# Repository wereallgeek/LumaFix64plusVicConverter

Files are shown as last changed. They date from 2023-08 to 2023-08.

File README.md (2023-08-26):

# LumaFix64 plus 85xx to 65xx VIC-II VDD selection
The LumaFix64 is not my design. 
This work is based on the brilliant work of Sven Peterson https://github.com/svenpetersen1965/LumaFix64
His version is based on <a href="https://www.lemon64.com/forum/viewtopic.php?t=40570&start=375">e5frog's LumaFix64 design</a>, which was released in March 7th, 2018 in the Lemon64.com forum. The changes in my design are:

* Added a VIC-II conversion to enable either shortboard or longboard voltages to the VIC-II, in order to be able to install 85xx VICs to an earlier (longboard) motherboard
* Added jumper to permit bypassing the C64 motherboard and push wires directly to the RF modulator unit (for aftermarker models that accepts it) in order to further reduce induced noise on the video lines

-- this design has not yet been tested

Sven advise that the Chroma potentiometer is not required but most LUMAFIX still includes it. If desired, it can be omitted, but this revision does not prepare solder points to do so, please use the potentiometer connections directly for that purpose. 

The LumaFix64 requires the precision round pin strips, because those are narrow enough not to break the socket of VIC-II chip. Since these pin strips are fragile, the LumaFix64 has to be handle with care.

Permission was initially received from e5frog for publishing these files, which was done in open hardware - the current development further enhance the design in pure open hardware ideology.

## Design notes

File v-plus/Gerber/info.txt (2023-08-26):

      
   
       Board: LumaFix64 v1.1sp (e5frog & http://www.lemon64.com)
       Rev.:  PLUS
  
       Files:
       ======
  
       All Gerber files are generated in extended gerber format (RS274X)
       *.TOP        : Film top copper
       *.BOT        :  -"- bottom copper
       *.STC        :  -"- top soldermask 
       *.STS        :  -"- bottom soldermask
       *.CRC        :  -"- cream top
       *.PLC        :  -"- silk screen top
       *.PLS        :  -"- silk screen bottom
       *.DK         : Drills plated Through (Excellon)
       *.NDK        : Drills not plated Through (Excellon)
       *.OUT        : Board outline

       Board Size:
       ===========
       Length     :   50.75 mm
       Width      :   25.94 mm
       Thickness  :   1.6 mm
       Material   :   FR 4
       Copper     :   35 um
       Surface    :   HASL
       
       Remarks:
       ========
       Drills not plated Through do not exsist on this board.
       drills >= 0.35mm
       width >= 8mil
       distance >= 6mil

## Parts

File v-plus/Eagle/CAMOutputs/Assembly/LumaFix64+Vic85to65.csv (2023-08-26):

Qty | Value | Device | Package | Parts | Description | POPULARITY
1 |  | IC-PACKAGE_DIL40GS40P | GS40P | SOCKET | Dual In Line
1 |  | IC-PACKAGE_DIL40_10120540 | BLK_10120540_2X20 | PINS | Dual In Line
2 |  | JP1E | JP1 | COLOR, S/LUM | JUMPER | 61
1 |  | JP2E | JP2 | SELECT-ONE | JUMPER | 34
1 | 100n | C-0805 | 0805 | C3
3 | 2k | TRIM_US-RJ9W | RJ9W | AEC, CHR, PHI0 | POTENTIOMETER | 1
2 | 47p | C-0805 | 0805 | C1, C2
1 | 74HCT14D | 74HCT14D | SO14 | IC1 | Hex schmitt trigger INVERTER
1 | OPEN_SOURCE_HW | OPEN_SOURCE_HW | OPENHW | U$13

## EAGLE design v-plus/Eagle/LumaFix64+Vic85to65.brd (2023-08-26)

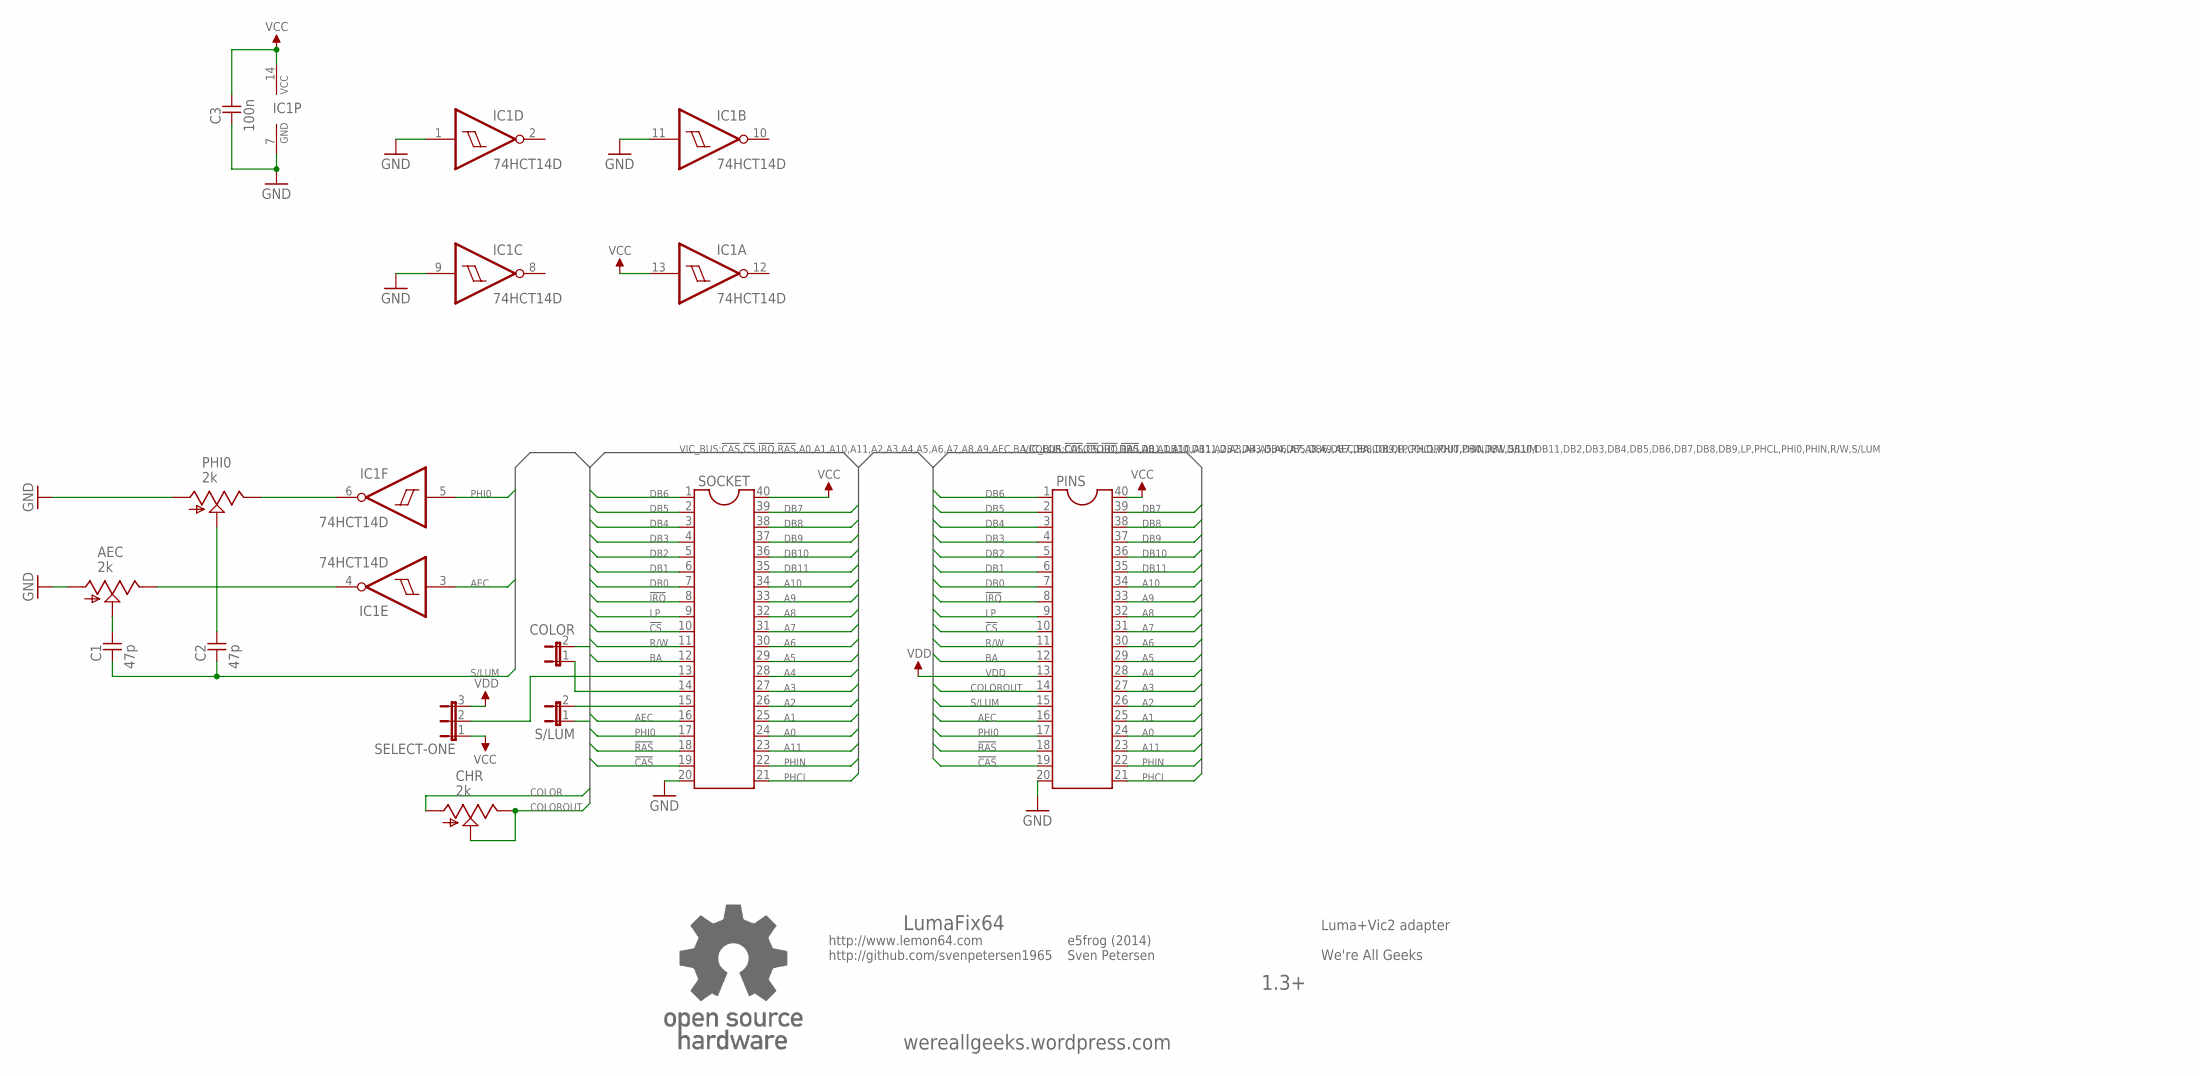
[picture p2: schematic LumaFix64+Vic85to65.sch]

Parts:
AEC: 2k; RJ9W
C1, C2: 47p; 0805
C3: 100n; 0805
CHR: 2k; RJ9W
COLOR: JP1E; JP1
IC1: 74HCT14D; SO14
PHI0: 2k; RJ9W
PINS: IC-PACKAGE_DIL40_10120540; BLK_10120540_2X20
S/LUM: JP1E; JP1
SELECT-ONE: JP2E; JP2
SOCKET: IC-PACKAGE_DIL40GS40P; GS40P
U$13: OPEN_SOURCE_HW; OPENHW

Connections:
!CAS: PINS.19, SOCKET.19
!CS: PINS.10, SOCKET.10
!IRQ: PINS.8, SOCKET.8
!RAS: PINS.18, SOCKET.18
A0: PINS.24, SOCKET.24
A1: PINS.25, SOCKET.25
A2: PINS.26, SOCKET.26
A3: PINS.27, SOCKET.27
A4: PINS.28, SOCKET.28
A5: PINS.29, SOCKET.29
A6: PINS.30, SOCKET.30
A7: PINS.31, SOCKET.31
A8: PINS.32, SOCKET.32
A9: PINS.33, SOCKET.33
A10: PINS.34, SOCKET.34
A11: PINS.23, SOCKET.23
AEC: IC1.3 (I), PINS.16, SOCKET.16
BA: PINS.12, SOCKET.12
COLOR: CHR.A, COLOR.2
COLOROUT: CHR.E, CHR.S, PINS.14
DB0: PINS.7, SOCKET.7
DB1: PINS.6, SOCKET.6
DB2: PINS.5, SOCKET.5
DB3: PINS.4, SOCKET.4
DB4: PINS.3, SOCKET.3
DB5: PINS.2, SOCKET.2
DB6: PINS.1, SOCKET.1
DB7: PINS.39, SOCKET.39
DB8: PINS.38, SOCKET.38
DB9: PINS.37, SOCKET.37
DB10: PINS.36, SOCKET.36
DB11: PINS.35, SOCKET.35
GND: AEC.A, C3.1, IC1.1 (I), IC1.7 (GND), IC1.9 (I), IC1.11 (I), PHI0.A, PINS.20, SOCKET.20
LP: PINS.9, SOCKET.9
unnamed: SELECT-ONE.2, SOCKET.13
unnamed: COLOR.1, SOCKET.14
unnamed: S/LUM.2, SOCKET.15
unnamed: AEC.S, C1.2
unnamed: C2.2, PHI0.S
unnamed: AEC.E, IC1.4 (O)
unnamed: IC1.6 (O), PHI0.E
PHCL: PINS.21, SOCKET.21
PHI0: IC1.5 (I), PINS.17, SOCKET.17
PHIN: PINS.22, SOCKET.22
R/W: PINS.11, SOCKET.11
S/LUM: C1.1, C2.1, PINS.15, S/LUM.1
VCC: C3.2, IC1.13 (I), IC1.14 (VCC), PINS.40, SELECT-ONE.1, SOCKET.40
VDD: PINS.13, SELECT-ONE.3

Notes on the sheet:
LumaFix64
http://www.lemon64.com http://github.com/svenpetersen1965
e5frog (2014) Sven Petersen
1.3+
Luma+Vic2 adapter
We're All Geeks
wereallgeeks.wordpress.com

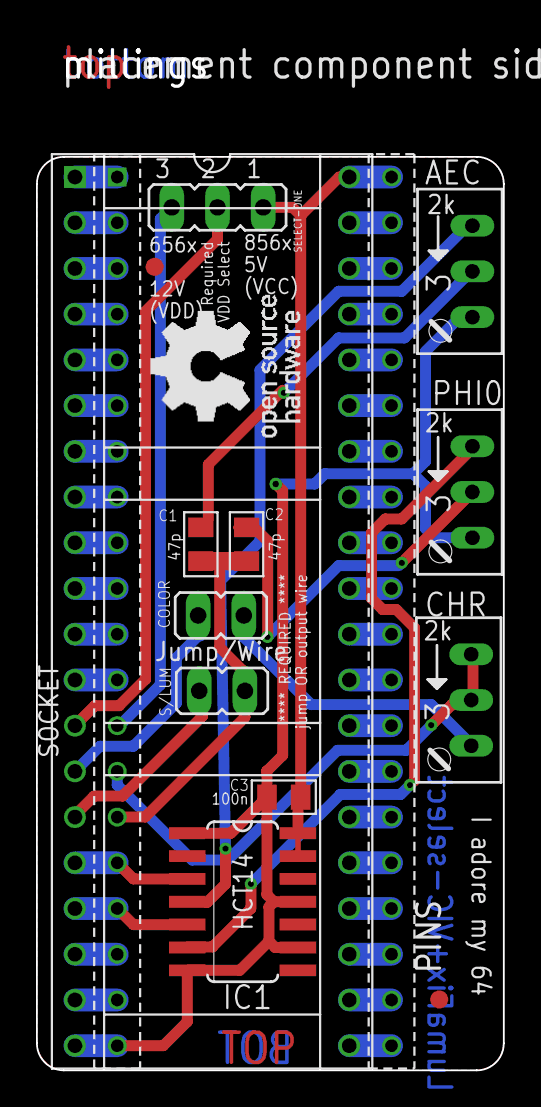
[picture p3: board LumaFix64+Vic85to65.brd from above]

Board: 2 copper layers, 25.9 x 50.8 mm, 17 parts (0 on the bottom side), 48 nets.

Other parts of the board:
U$7: 2LAYER
U$9: PCB-TITLE/
U$10, U$11: SMD_REF_R1MM

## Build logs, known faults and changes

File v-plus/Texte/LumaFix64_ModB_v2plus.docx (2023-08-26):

LumaFix64 Rev. 1.2sp

Module Description

# 1. Preface

It is a known fact, that some digitals signals are interfering with the video output signals inside the VIC-II chip of the Commodore C64. This results in a typical vertical strip pattern in the monitor output of the C64. The main culprits are AEC and PHI0 (VIC-II pin 16 and 17).

This topic was discussed in the lemon64.com forum in December 2011 (https://www.lemon64.com/forum/viewtopic.php?t=40570&start=0), where the attempt to cancel out these interferences was mentioned, that was released by the user ikary_01 in forum64.de in October 2010, called „C64-Streifenfix“ (https://www.forum64.de/index.php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 (https://www.forum64.de/index.php?s=b329abcb4ddda3e4efab6bcffade57ad2a5b7f33) & https://sd2snes.de/~ikari/pics/ ).

This design is based on the eagle files LumaFix64v1.0_B64W, that e5frog released in the lemon64.com forum March 7th, 2018. (https://www.lemon64.com/forum/viewtopic.php?t=40570&start=375)

# 2. Functionality

The signals AEC and PHI0 are inverted, then attenuated by potentiometers (AEC & PHI0) and coupled into the S/LUM signal (VIC-II pin 15) via a small (47p) capacity). The potentiometers can be adjusted to minimize the interferences of the signals mentioned above.

Further on, the chrominance signal of the VIC-II chip has an amplitude, which is too high for most modern TVs, which results in a poor color quality. Many C64 video cables solve this issue by inserting a 330Ω resistor into the chrominance output signal. The LumaFix64 solves this issue with a pot (CHR) inserted in the signal. This pot can stay not populated and the cut pad CP1 can be closed instead.

# 3. Revision History

## v1.0 B64W → v1.1sp

- The issue of the original eagle files with Eagle 9 was fixed
- The schematic was restructured
- The THT ICs and capacitors were left out
- The footprints of the socket, pin headers and pots were changed
- The inverter IC 74HCT14 has a 100n buffer cap
- The cut-pad CP1for bridging the CHR pot was added, a 330Ω resistor (0603) can be placed on this cut-pad for having a fix resistor in the chrominance output.
- The width of the board was reduced to 25.94mm
- The layout is new

## v1.1sp → v1.2sp

- PCB Revision
- R1 is new to replace the CHR pot if not required

## v1.2sp → v2plus

- PCB Revision
- Removed R1 and bypass jumpers for CHR
- Changed potentiometers to inline 3-pin style
- Added VIC-II VDD voltage select
- Added passtrough/wire jumpers for VIC-II output

LumaFix64_ModB_v1_2sp.docx 03.04.2020 14:15 Erstellt von Sven Petersen Seite 2 von 2 Dok.-Nr.: 000-8-00-00

LumaFix64_ModB_v1_2sp.docx 03.04.2020 14:15 Drafted by Sven Petersen Page 1 of 1 Doc.-No.: 110-6-01-01.2sp

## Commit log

2023-08-26 Initial revision. Addition - VIC-II conversion from 85xx to 65xx motherboard Addition - output jumpers Change - removal of CHR options. Can be implemented directly on pot pins Change - changed potent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
    [LumaFix64+Vic85to65.brd, LumaFix64+Vic85to65.csv, LumaFix64+Vic85to65.sch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]
2023-08-26 removal of initial v1.2 - still available at the source branch.
    [LumaFix64_v1_2sp_bom.xlsx, LumaFix64_v1_2sp_calc.xlsx, LumaFix64v1.2_sp.brd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]
